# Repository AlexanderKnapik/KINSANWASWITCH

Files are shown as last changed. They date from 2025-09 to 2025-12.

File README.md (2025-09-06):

Stand With Ukraine (https://vshymanskyy.github.io/StandWithUkraine)

# KINSANWASWITCH

DIY-friendly photointerrupter microswitch/lamp holder 2-in-1 for generic 100mm Chinese arcade buttons. Enables an OBSA-LHSXF+OBSA-100UMQ-like setup at low cost with generic parts.

## Updates
- This is branch of beta-version SHINSANWASWITCH update version 1.1 with some optimizations that needs to be verified, so now everything is divided into two branches: *main* with stable version 1.0 and version1.1 in *beta* . If you want currently stable version - use *main* branch. 
Version 1.1 has some optimizations in body of SHINSANWASWITCH and possibility to make different variants of PCB to make with possibility to make one-layered-board at home (if you have enough skill). More info here:  https://www.projectdiva.net/community/threads/shinsanwaswitch-blog-of-creating-diy-analog-of-obsa-lhsxf-ln.2325/page-2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

## Parts list

### Electrical
Details about PCB and it's variants can be found in [readme in pcb thread](pcb/README.md)

- PCB: 1x `PCB` **1mm thickness** (KiCad 5.99+ (5.99.0-12455-g28bd734313), release build required for exporting Gerber files or take Gerber files archive in `gerber/shinsanwaswitch.zip`)
  - C1: Generic 0.1uF through hole ceramic capacitor.
  - C2: *not necessary, but recommended* 47uF 6.3v electrolitic capacitor on the power line input (read [some nuances of board assembly](https://github.com/steelpuxnastik/SHINSANWASWITCH/tree/version1.1/pcb#some-nuances-of-board-assembly) for more ditails)
  - STI1: `NSI45020AT1G` (for standard and one-layered-board with LED driver board versions) or R4: 470ohm 5% 1/4W through hole (for one-layered-board with resistor and 12v power-up 20mA LED, in other case use calculation to know what resistor you need to use)
  - J1: `S5B-PH-K-S` or equivalent.
  - LED: `S2B-PH-K-S` or equivalent.
  - PC1: `RPI-352`.
  - Q1: `2SC5395-F` or equivalent (may be rare but can be found on e.g. aliexpress).
  - R1: 330ohm 5% 1/4W through hole.
  - R2: 22kohm 5% 1/4W through hole.
  - R3: 10kohm 5% 1/4W through hole.
- 1x harness
  - 5x Single-ended **JST PH** wires (can be found on e.g. aliexpress or alternatively you can crimp them yourself, I recommend you to found on aliexpress for it 5pin 22 AWG white-blue-red-green-black cable, it amazingly fits connector, feels very reliable and also fits into the understandable color scheme)
  - 1x JST `PHR-5` or equivalent.
- 1x LED assembly (no resistors required)
  - 2x **JST PH** to **.1" (BLS-02/Dupont 2pin) female** wires (can be found on e.g. aliexpress or alternatively you can crimp them yourself. I recommend to use wires flexible as possible, that will be very useful. Wires length - somewhere around ~150-160mm, need be shorter as possible, because long wires will be nowhere to fold. Can be made by soldering single-ended JST PH wire and .1" (BLS-02/Dupont 2pin) female wire together and wrapping each wire with heat shrink tubing).
  - 1x 20mA through hole white LED (plugs into the .1" (BLS-02/Dupont 2pin) female connector).
  - 1x JST `PHR-2` or equivalent.
  - 1x 2 pin .1" (BLS-02/Dupont 2pin) female connector housing.
  
### Pin mapping

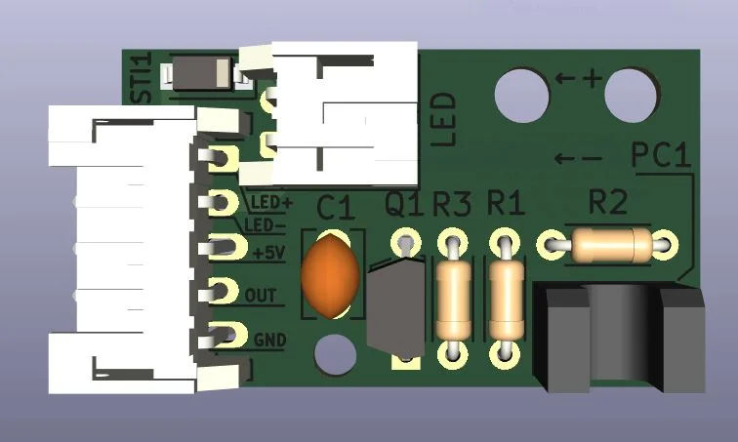
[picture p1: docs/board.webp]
board


I/O port (from up to down):

| \#  | Description |
| --- | --- |
|  1  | LED+ |
|  2  | LED- |
|  3  | +5V |
|  4  | OUT |
|  5  | GND |

LED connector (from up to down):

| \#  | Description |
| --- | --- |
|  1  | + |
|  2  | - |

### Mechanical

- 3D printable parts (printing in resin recommended for best accuracy but not required)
  - 1x `STL/body.STL`
  - 1x `STL/cap.STL`
  - 3x `STL/lever_*.STL` (because of possible differences of generic 100mm Chinese arcade buttons and possible differences in preferences of players that will use it there available 3 different lengts of levers that you should print separately (and better in different colors) and then determine from your own experience what is best for you)
	- 1x `STL/lever_long.STL`
	- 1x `STL/lever_middle.STL`
	- 1x `STL/lever_short.STL`
- 1x 0.3x6x10mm (wire thickness x outer diameter x length) spring (can be found on e.g. aliexpress).
- 2x M2x8 screws

### Example of 3D-print settings that were used
- Layer height: 0.12mm (can be less, but not more, because quality depends on it)
- Nozzle: 0,4mm (can be less, of course)
- Fill level: 25%
- Number of wall lines: 4
- Number of cover layers: 4
- Number of bottom layers: 4
- Supports: only from the bed
- Filament: PETG
- Color: any, but the lever must be black or the part of lever that crosses the optocoupler must be painted with a marker in black in several layers, otherwise the optocoupler will work incorrectly and the switch will not work correctly.

## Source files
In folder `source` there are available source files that used to create 3D-models in SolidWorks. You can use them to make your modification, if you need it.

Original 100mm arcade button Solidworks source files taken from https://grabcad.com/library/100mm-button-1 and very helped me to make this thing.

# Known issues 
At this moment there is no possibility to connect SHINSANWASWITCH (and its active board) to regular matrices, where used connection between different pins, but not pin to ground that used here. If you know how to get around this problem - please, write about that in our issues thread: https://github.com/steelpuxnastik/SHINSANWASWITCH/issues/1

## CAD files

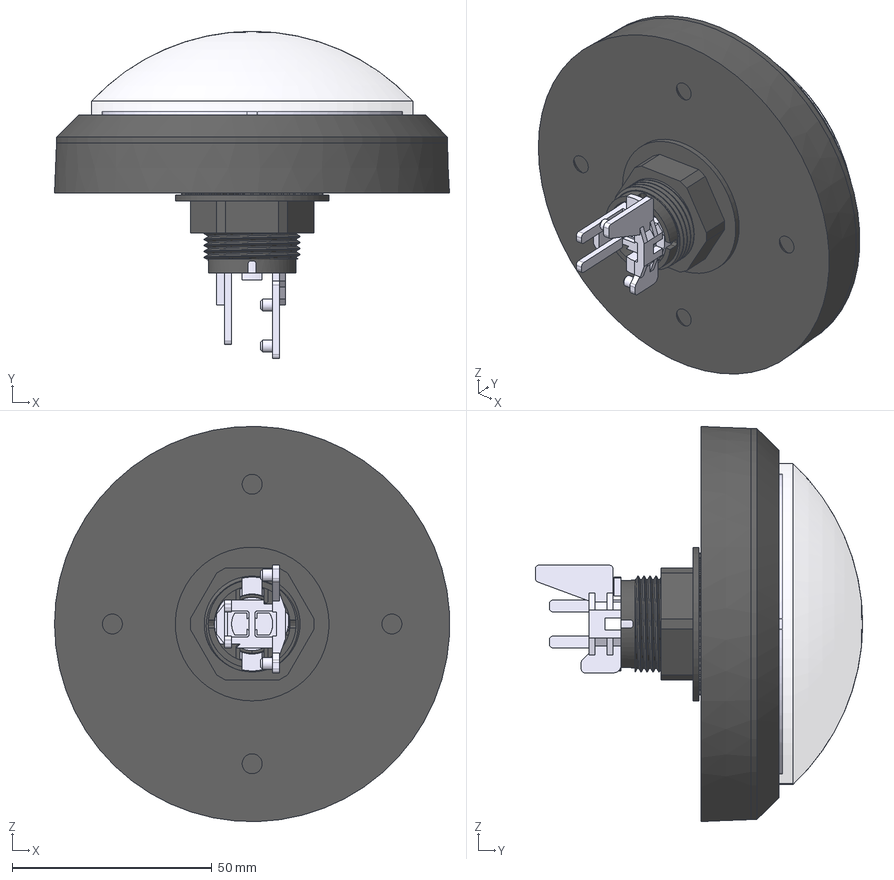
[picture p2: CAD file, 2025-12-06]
mech/Samducksa CWB 401 Assembly.step
98.9 x 82.0 x 99.0 mm
LCS_Origin007
LCS_Origin
LCS_1
BaseBody
LCS_Origin001
PlungerBody
LCS_4
LCS_10
LCS_2
LCS_9
LCS_Origin002
DiffuserBody
LCS_5
LCS_Origin005
CapBody
LCS_3
LCS_Origin004
NutBody
LCS_7
LCS_Origin006
Spring_25mm_14.7mm_OD
LCS_Origin009
ButtonBody
LCS_Mount
LCS_Origin010
LCS_Button_Base
LCS_Mount_2
LCS_Mount_1
LCS_LED_Base
LampHolderBody

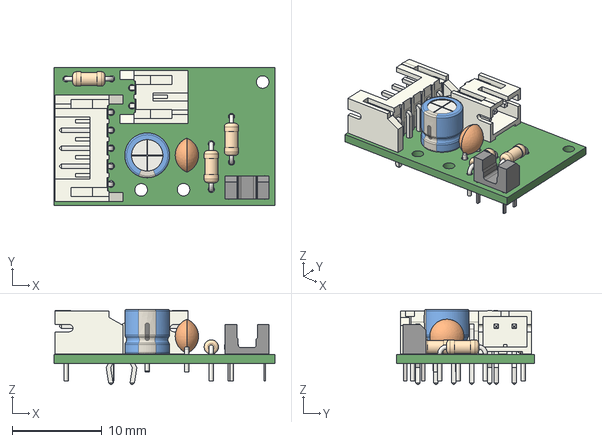
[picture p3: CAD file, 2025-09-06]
pcb/kinsanwaswitch.step
24.6 x 15.4 x 8.40 mm

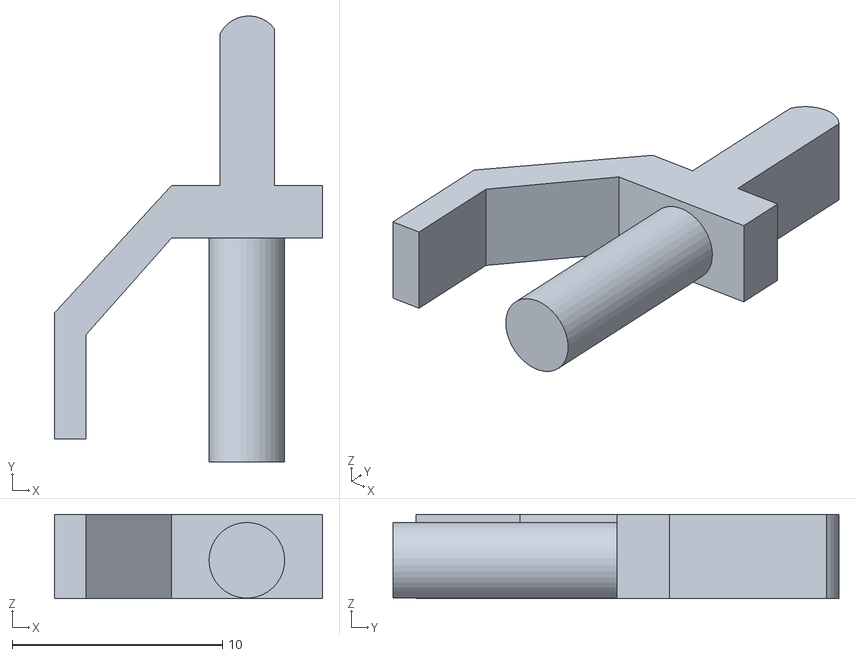
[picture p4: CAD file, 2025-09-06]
stl/lever_long.STL
12.8 x 21.2 x 4.00

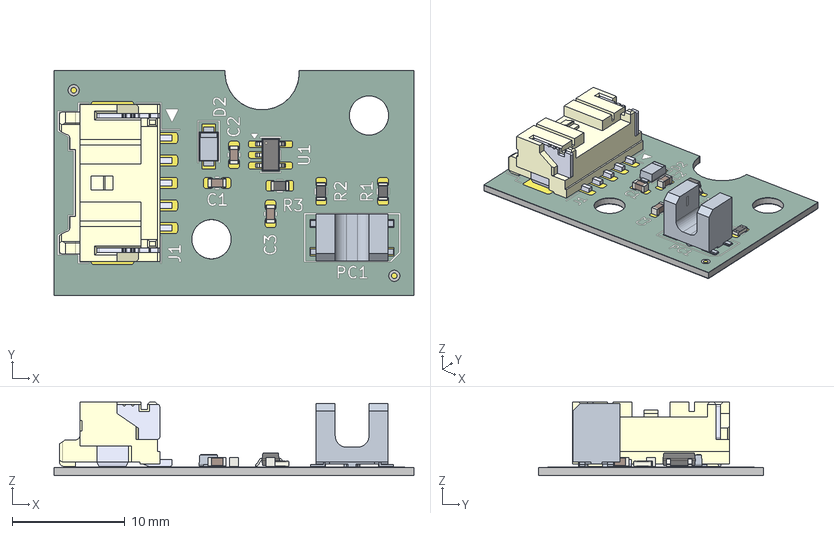
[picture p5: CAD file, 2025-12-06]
mech/kinsanwaswitch_pcb.step
32.0 x 20.0 x 6.54 mm
R_0603_1608Metric x 3
C_0603_1608Metric x 3
SC-74A-5_1.55x2.9mm_P0.95mm
kinsanwaswitch_pcb 1.7.1
RPI-0352E
SM05B-PASS-TBT
kinsanwaswitch_copper
kinsanwaswitch_silkscreen
kinsanwaswitch_soldermask x 2
kinsanwaswitch_PCB

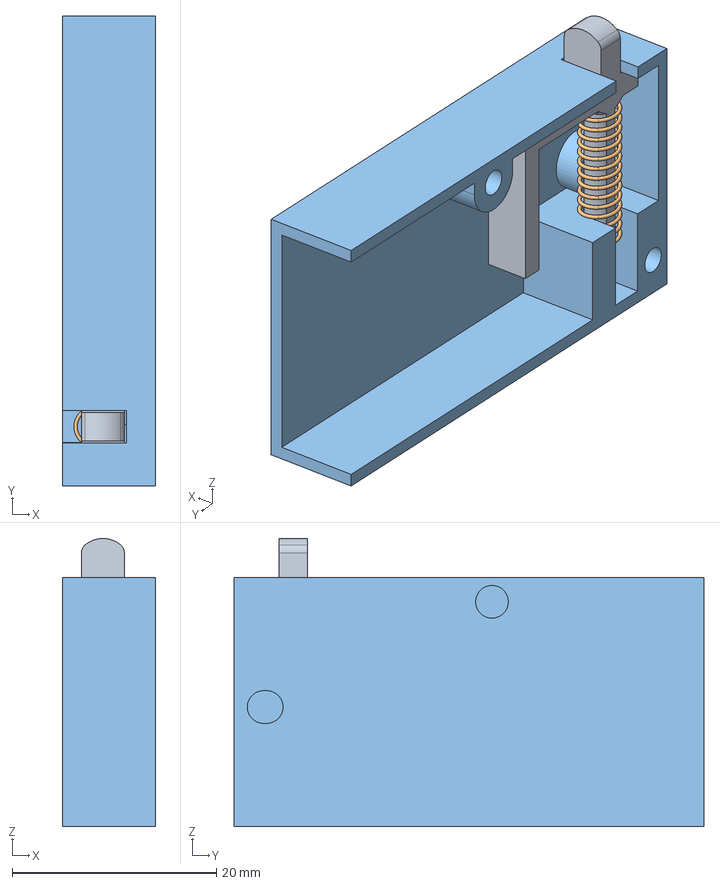
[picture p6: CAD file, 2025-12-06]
mech/KinSanwaSwitch.FCStd
9.10 x 46.0 x 28.2 mm
Kin Lever
Spring_5mm
Enclosure Body

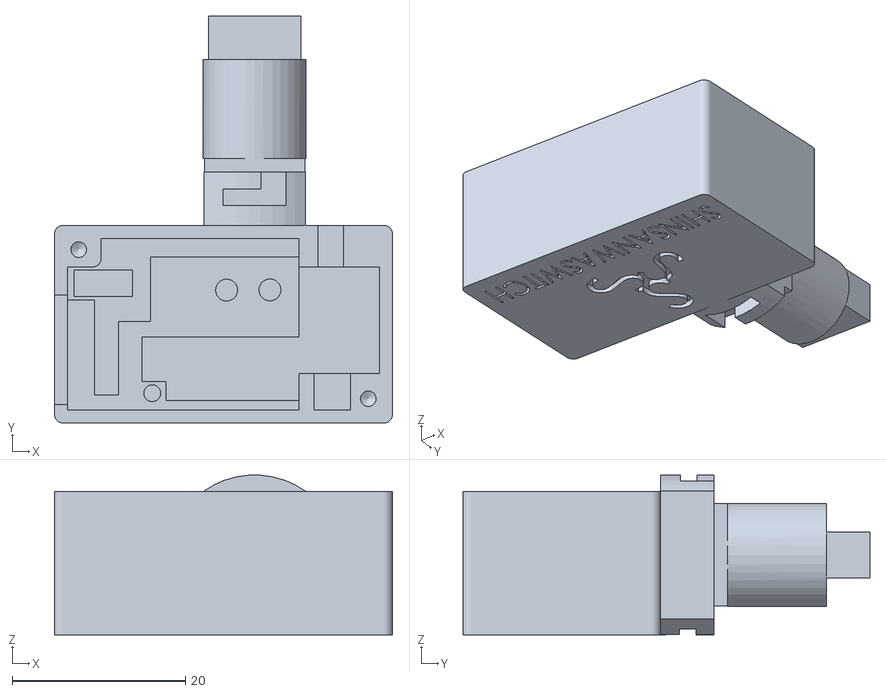
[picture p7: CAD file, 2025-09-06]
stl/body.STL
39.0 x 47.0 x 18.4

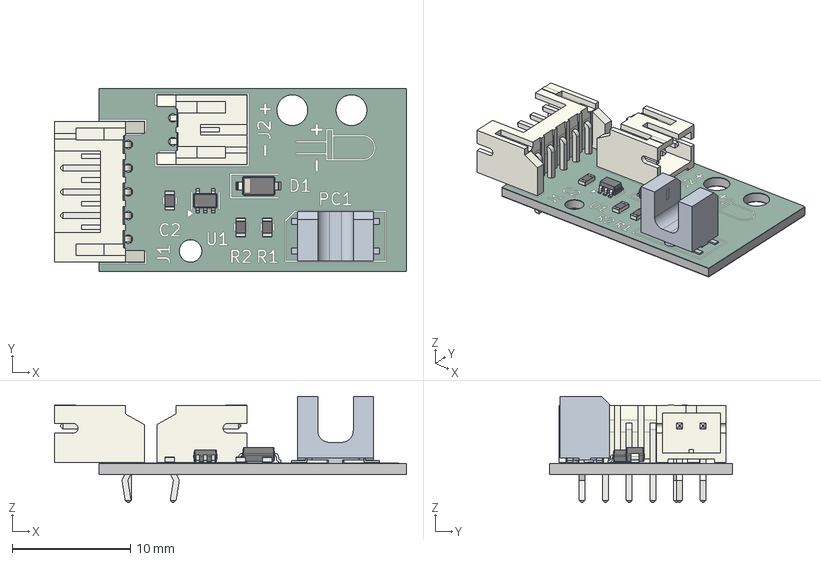
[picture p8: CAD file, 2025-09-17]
mech/pcb.step
29.8 x 15.5 x 9.00 mm
D_SOD-123
R_0603_1608Metric x 3
SOT-353_SC-70-5
JST_PH_S5B-PH-K_1x05_P2.00mm_Horizontal
RPI-0352E
JST_PH_S2B-PH-K_1x02_P2.00mm_Horizontal
kinsanwaswitch_copper
kinsanwaswitch_silkscreen
kinsanwaswitch_soldermask
kinsanwaswitch_PCB

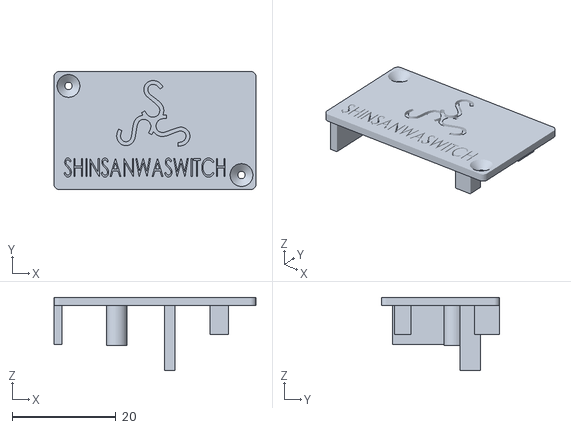
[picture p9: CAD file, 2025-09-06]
stl/cap.STL
39.0 x 22.8 x 14.1

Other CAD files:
mech/Samducksa CWB 401.FCStd
stl/lever_middle.STL
stl/lever_short.STL
mech/KinSanwaSwitch PCB.FCStd

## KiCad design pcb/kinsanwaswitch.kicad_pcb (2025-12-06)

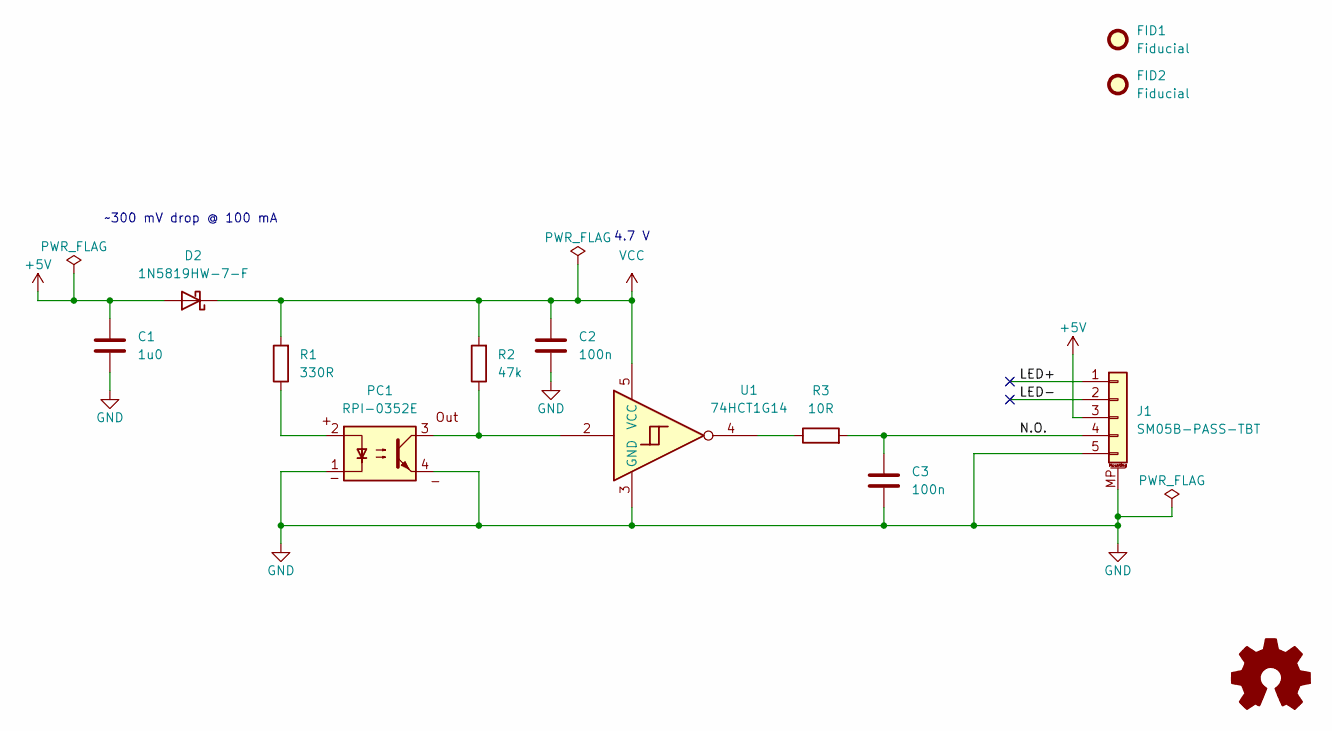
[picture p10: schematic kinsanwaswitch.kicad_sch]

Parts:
C1: 1u0; C_0603_1608Metric
C2, C3: 100n; C_0603_1608Metric
D2: 1N5819HW-7-F; D_SOD-123
FID1, FID2: Fiducial; Fiducial_0.5mm_Mask1mm
J1: SM05B-PASS-TBT; JST_PH_S5B-PH-SM4-TB_1x05-1MP_P2.00mm_Horizontal
PC1: RPI-0352E; Rohm_RPI-0352E
R1: 330R; R_0603_1608Metric
R2: 47k; R_0603_1608Metric
R3: 10R; R_0603_1608Metric
SYM1: Logo_Open_Hardware_Small; OSHW-Logo_5.7x6mm_SilkScreen
U1: 74HCT1G14; SC-74A-5_1.55x2.9mm_P0.95mm

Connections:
+5V: C1.1, D2.2 (A), J1.3
/LED+: J1.1
/LED-: J1.2
/N.O.: C3.1, J1.4, R3.2
GND: C1.2, C2.2, C3.2, J1.5, J1.MP (MountPin), PC1.1, PC1.4, U1.3 (GND)
unnamed: PC1.2, R1.1
unnamed: PC1.3, R2.1, U1.2
unnamed: R3.1, U1.4
VCC: C2.1, D2.1 (K), R1.2, R2.2, U1.5 (VCC)

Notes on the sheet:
4.7 V
~300 mV drop @ 100 mA

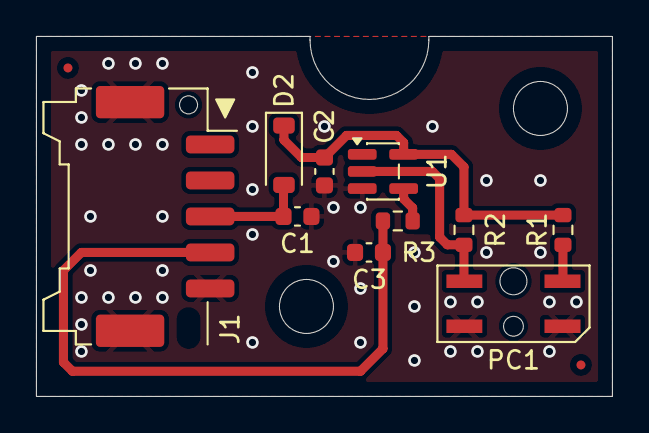
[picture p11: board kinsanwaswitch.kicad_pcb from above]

Board: 2 copper layers, 32.0 x 20.0 mm, 13 parts (1 on the bottom side), 7 nets.

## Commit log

2025-09-06 new hardware design
    Using a schmitt trigger inverter over the second open collector NPN
    transistor. Redid the PCB layout to use surface mount components over
    through hole and aligned all components to a grid.
    [kinsanwaswitch.kicad_pcb, kinsanwaswitch.kicad_sch, kinsanwaswitch.step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]
2025-09-06 add name and dates to sheets
    [kinsanwaswitch.kicad_pcb, kinsanwaswitch.kicad_sch]
2025-09-06 rearrange folder structure
    Split the source folder into the mechanicals (mech) and the images in
    the README.md file (docs).
    [BLS-02.SLDPRT, LED.SLDASM, LED_BASE.SLDPRT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]
2025-09-17 generate pcb 3d step file
    [pcb.step]
2025-09-17 3d model samducksa cwb 401 switch
    [Samducksa CWB 401.FCStd]
2025-12-06 model cwb401 lamp holder
    [Samducksa CWB 401 Assembly.step, Samducksa CWB 401.FCStd]
2025-12-06 revision 1.0 PCB
    [kinsanwaswitch-B_Cu.gbr, kinsanwaswitch-B_Mask.gbr, kinsanwaswitch-B_Silkscreen.gbr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]
2025-12-06 initial enclosure modelling
    Modelled the spring plunger and the PCB cavity so far.
    [KinSanwaSwitch PCB.FCStd, KinSanwaSwitch.FCStd, kinsanwaswitch_pcb.step]
